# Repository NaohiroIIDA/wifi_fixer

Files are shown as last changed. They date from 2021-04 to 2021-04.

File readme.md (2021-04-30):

# wifi_fixer_esp8266
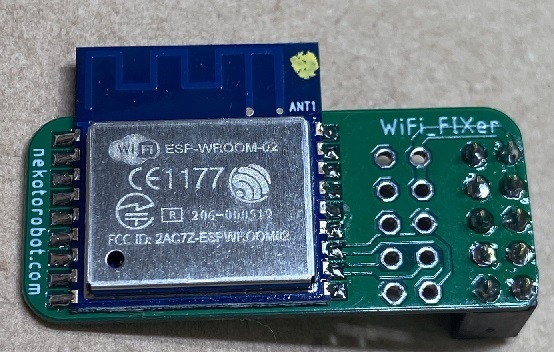
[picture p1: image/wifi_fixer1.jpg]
wifi_fixer


## What is this?
"wifi_fixer" is an ESP8266 board for changing the Wifi-setting of Raspberry Pi from the outside using a smartphone.

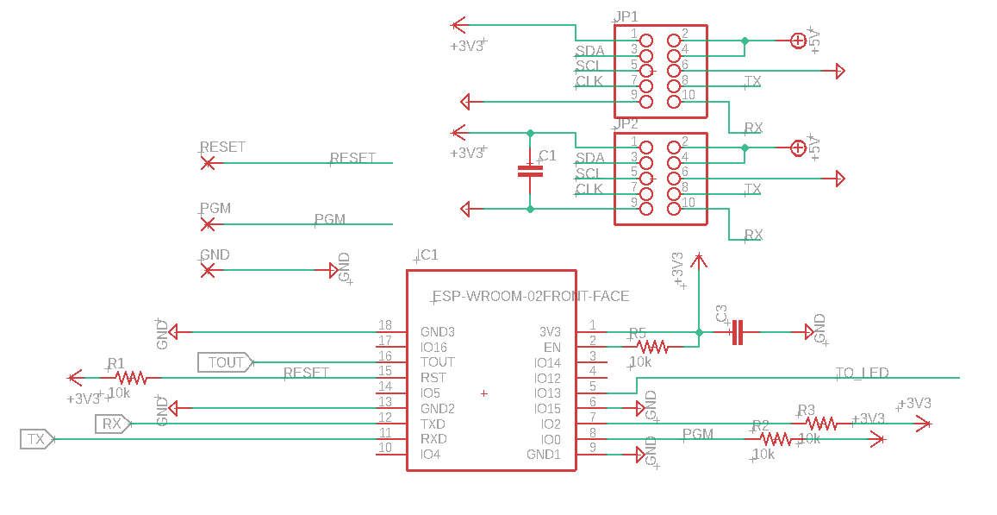
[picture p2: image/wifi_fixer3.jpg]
wifi_fixer
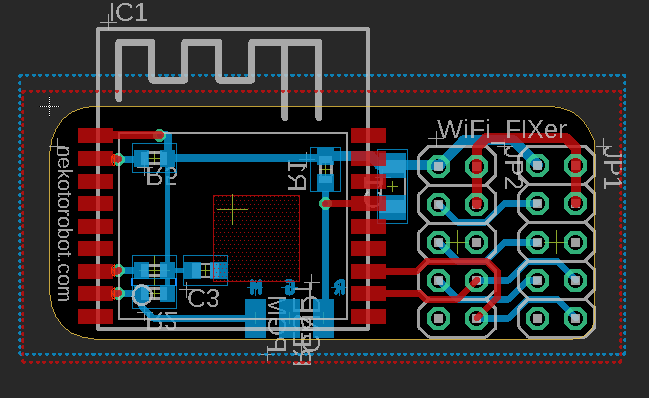
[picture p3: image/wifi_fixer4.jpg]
wifi_fixer
 

## How does it work?
Wifi_fixer acts as an independent wifi access point. 
When you connect to this, the module show this by web browser. 
Enter the SSID / PASS of the external access point through this menu.

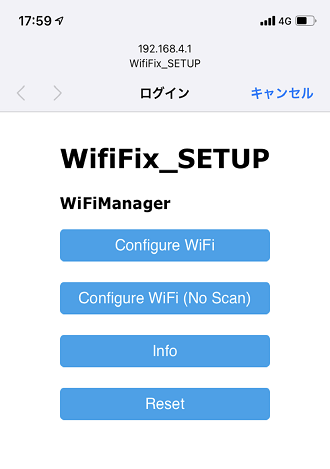
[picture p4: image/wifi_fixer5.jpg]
wifi_fixer5

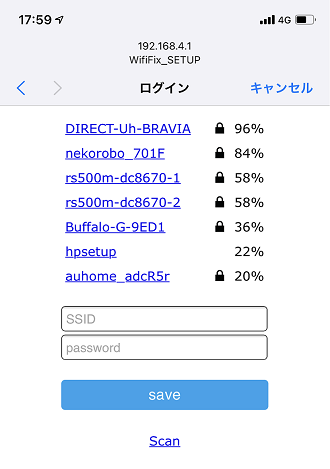
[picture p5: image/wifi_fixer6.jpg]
wifi_fixer6


Raspberry Pi connect by  "/dev/serial0" (PIN:Tx RX)

### wifi_fixer.py
- Check Wifi is available
    - wifi_fixer module wait enter new SSID / PASS 
    - new SSID / PASS is entered, add to /etc/wpa_supplicant/wpa_supplicant.conf
    - Restart the raspberry pi

## Limits
--Only 2.4GHz wifi can be detected.
--If you have a large number of access points, you may not be able to find them.

## これは何？
ラズベリーパイのWifi設定を外部からスマートフォンを使って変更するためのESP8266ボード "wifi_fixer"です。

## どうやって動く？
Wifi_fixerは独立したwifiアクセスポイントとして動作します。スマートフォンでこのアクセスポイントに接続すると
内蔵したウェブサーバーを使ってメニューを表示します。このメニューを通じて外部のアクセスポイントのSSID/PASSの入力を行います。
ラズベリーパイとはTx/RXピンを通じ、/dev/serial0　を使ってシリアル通信を行います。

### wifi_fixer.py 
- Wifiが使用可能か調べる
- wifi_fixer モジュールにシリアル通信で問い合わせを行い、SSID/PASSが入力されているか調べる
- 新しいSSID/PASSが入力されたら、/etc/wpa_supplicant/wpa_supplicant.conf に追記
- ラズベリーパイをリスタート

## 制限
- 検出できるのは2.4GHz wifiのみです。
- 多数のアクセスポイントがある場合、発見できないことがあります。

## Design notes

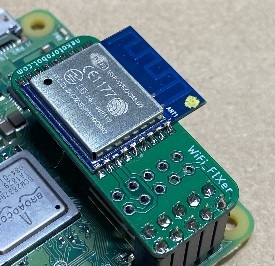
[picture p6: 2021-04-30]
image/wifi_fixer2.jpg

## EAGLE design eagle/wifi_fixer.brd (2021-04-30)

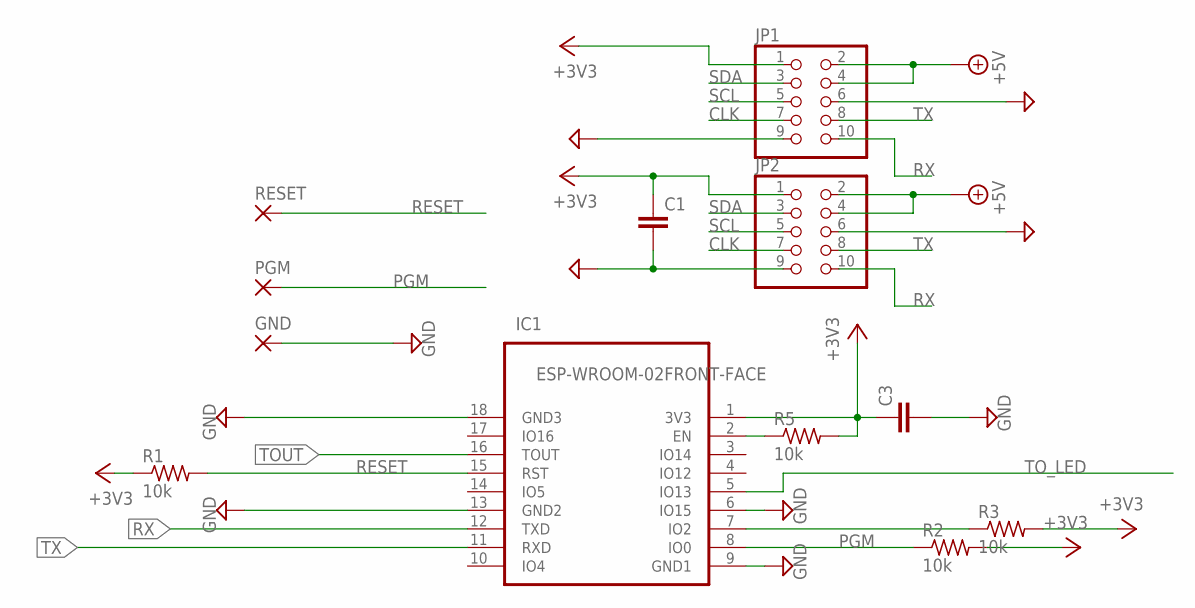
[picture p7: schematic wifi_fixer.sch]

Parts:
C1: C-EUC1206; C1206
C3: C-EUC0603; C0603
GND: SMD2; SMD1,27-2,54
IC1: ESP-WROOM-02FRONT-FACE; FRONT-FACE
JP1, JP2: PINHD-2X5; 2X05
PGM: SMD2; SMD1,27-2,54
R1, R2, R3, R5: 10k; R0603
RESET: SMD2; SMD1,27-2,54

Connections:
+3V3: C1.1, C3.1, IC1.1 (3V3), JP1.1, JP2.1, R1.1, R2.2, R3.2, R5.2
+5V: JP1.2, JP1.4, JP2.2, JP2.4
CLK: JP1.7, JP2.7
GND: C1.2, C3.2, GND.1, IC1.6 (IO15), IC1.9 (GND1), IC1.13 (GND2), IC1.18 (GND3), JP1.6, JP1.9, JP2.6, JP2.9
unnamed: IC1.7 (IO2), R3.1
unnamed: IC1.2 (EN), R5.1
PGM: IC1.8 (IO0), PGM.1, R2.1
RESET: IC1.15 (RST), R1.2, RESET.1
RX: IC1.12 (TXD), JP1.10, JP2.10
SCL: JP1.5, JP2.5
SDA: JP1.3, JP2.3
TOUT: IC1.16 (TOUT)
TO_LED: IC1.5 (IO13)
TX: IC1.11 (RXD), JP1.8, JP2.8

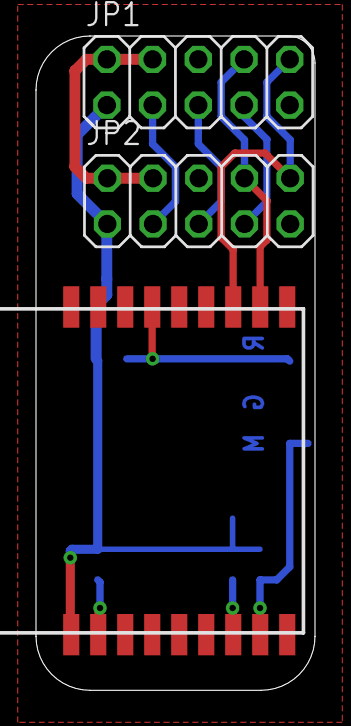
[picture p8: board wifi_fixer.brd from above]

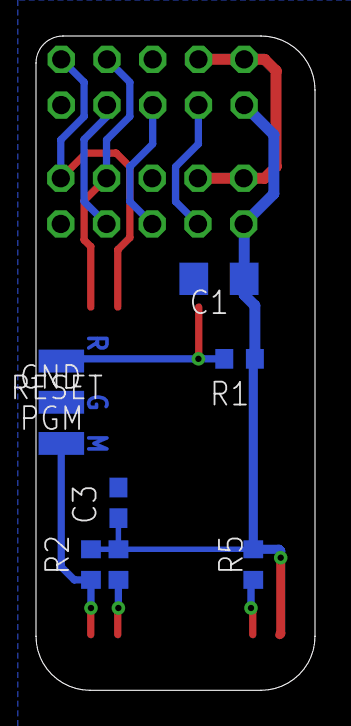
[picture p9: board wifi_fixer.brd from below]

Board: 2 copper layers, 15.5 x 36.4 mm, 12 parts (9 on the bottom side), 12 nets.

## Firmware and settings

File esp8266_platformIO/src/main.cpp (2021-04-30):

#include <ESP8266WiFi.h>          //https://github.com/esp8266/Arduino

//needed for library
#include <DNSServer.h>
#include <ESP8266WebServer.h>
#include <WiFiManager.h>         //https://github.com/tzapu/WiFiManager

#define TRIGGER_PIN 4

String ssid;
String pass;

int incomingByte = 0;	// 受信データ用

void setup() {
    // put your setup code here, to run once:
    IPAddress ip;

    pinMode(TRIGGER_PIN, INPUT_PULLUP);
    Serial.begin(115200);

    //Serial.println("Start");
    delay(3000);


    //WiFiManager
    //Local intialization. Once its business is done, there is no need to keep it around
    WiFiManager wifiManager;

    wifiManager.setDebugOutput(false);

    //if ( digitalRead(TRIGGER_PIN) == LOW ) {
      //reset saved settings
    
      //Serial.println("RESET");
    wifiManager.resetSettings();

    //}

    
    //set custom ip for portal
    //wifiManager.setAPStaticIPConfig(IPAddress(10,0,1,1), IPAddress(10,0,1,1), IPAddress(255,255,255,0));

    //fetches ssid and pass from eeprom and tries to connect
    //if it does not connect it starts an access point with the specified name
    //here  "AutoConnectAP"
    //and goes into a blocking loop awaiting configuration
    wifiManager.autoConnect("WifiFix_SETUP");
    //or use this for auto generated name ESP + ChipID
    //wifiManager.autoConnect();

    
    //if you get here you have connected to the WiFi
    // Serial.println("connected!!");

    ssid = wifiManager.getSSID();
    pass = wifiManager.getPassword();

   

}

void loop() {
    // put your main code here, to run repeatedly:

    if (Serial.available() > 0) { 
		incomingByte = Serial.read(); 

    //if( incomingByte == 0x0a)
    //{
      // Serial.print("SSID:\t");
      // Serial.println(ssid);

      // Serial.print("PASS:\t");
      // Serial.println(pass);

      Serial.print(ssid);
      Serial.print(",");
      Serial.println(pass);
      
    // }

		
	}
}

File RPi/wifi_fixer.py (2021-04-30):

import os
import time
import serial


def ESP_check():

    ser = serial.Serial('/dev/serial0', 115200, timeout=3)

    time.sleep(1)
    ser.write(11)

    dummy = ser.readline().decode()
    rim = dummy.split(',')

    if len(rim) > 1:
        #        print("SSID:", rim[0], "  PASS:", rim[1])
        return rim
    else:
        #        print("No data")
        rim = []
        return rim


def CreateWifiConfig(SSID, password):
    config = (
        '\nnetwork={{\n' +
        '\tssid="{}"\n' +
        '\tpsk="{}"\n' + '}}').format(SSID, password)

    print(config)
    with open("wpa_supplicant.conf.edit", "a+") as wifi:
        wifi.write(config)
    wifi.close()
    print("Wifi config added")


def CheckWPAfile(SSID, PASS):

    check = 0
    ssid_txt = ""
    pass_txt = ""

    with open("/home/pi/wpa_supplicant.conf.edit") as wifi:

        while True:
            line = wifi.readline()
            if not line:
                break

            if 'ssid' in line:
                ul = line.split('"')
                ssid_txt = ul[1]

            if 'psk' in line:
                ul = line.split('"')
                pass_txt = ul[1]

            if ssid_txt == SSID and pass_txt == PASS:
                check = 1

        return check


response = os.system("sudo ping -c 1 google.com")

if response != 0:
    print 'system is not connected!'
    response = os.system("sudo ifconfig wlan0 down")
    response = os.system(
        "sudo cp /etc/wpa_supplicant/wpa_supplicant.conf /home/pi/wpa_supplicant.conf.edit")

    esp = ESP_check()
    if len(esp) != 0:
        print(esp[0].strip(), esp[1].strip())

        if CheckWPAfile(esp[0].strip(), esp[1].strip()):
            print("find")

        else:
            print("diff!")

            CreateWifiConfig(esp[0].strip(), esp[1].strip())
            response = os.system(
                "sudo cp /home/pi/wpa_supplicant.conf.edit /etc/wpa_supplicant/wpa_supplicant.conf")
            response = os.system("sudo reboot")

    response = os.system("sudo ifconfig wlan0 up")

    while True:
        res2 = os.system("sudo ping -c 1 google.com")
        time.sleep(1)
        if res2 == 0:
            print 'Connected'
            break
